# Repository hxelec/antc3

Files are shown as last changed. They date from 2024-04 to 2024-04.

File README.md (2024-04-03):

These are the files for the 150g antweight combat robot I recently made. I made an all-in-one robot controller, which is, in my opinion, a better alternative to the Malenki-Nano and Malenki-HV, and a very low-cost ESP-NOW remote. The high-quality PCBs for this project were manufactured by PCBWay, and if you use my link to sign up: https://pcbway.com/g/x5f10h, you can get $5 off your first order and help support this (partially) open-source development. You can check out the video for this project on my YouTube channel: https://youtube.com/@hxtec32?si=qvrlxVD-KIIIB9TC
The code does not have failsafe, and doesn't drive the robot fully straight by the way, but feel free to use it as a reference for bidirectional ESP-NOW communication. I would recommend reading this article too, as I adapted the code for my own use case: https://randomnerdtutorials.com/esp-now-two-way-communication-esp32/
By the way, you need the necessary Arduino files for a T-QT Pro before using my code, because it won't work if otherwise. The T-QT Pro is great for this project.

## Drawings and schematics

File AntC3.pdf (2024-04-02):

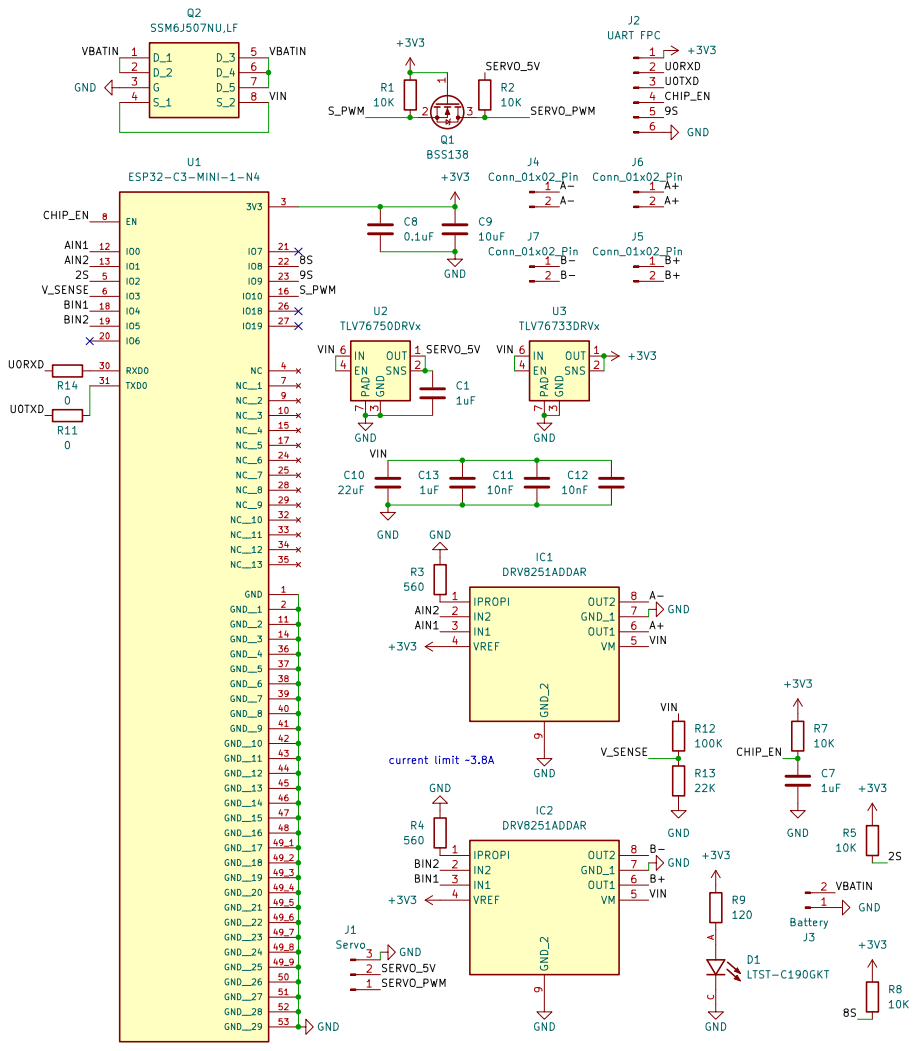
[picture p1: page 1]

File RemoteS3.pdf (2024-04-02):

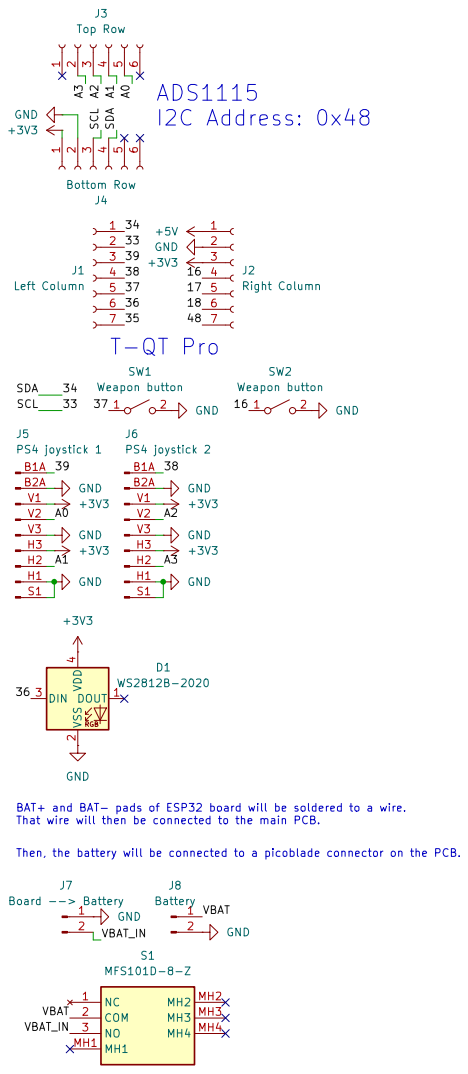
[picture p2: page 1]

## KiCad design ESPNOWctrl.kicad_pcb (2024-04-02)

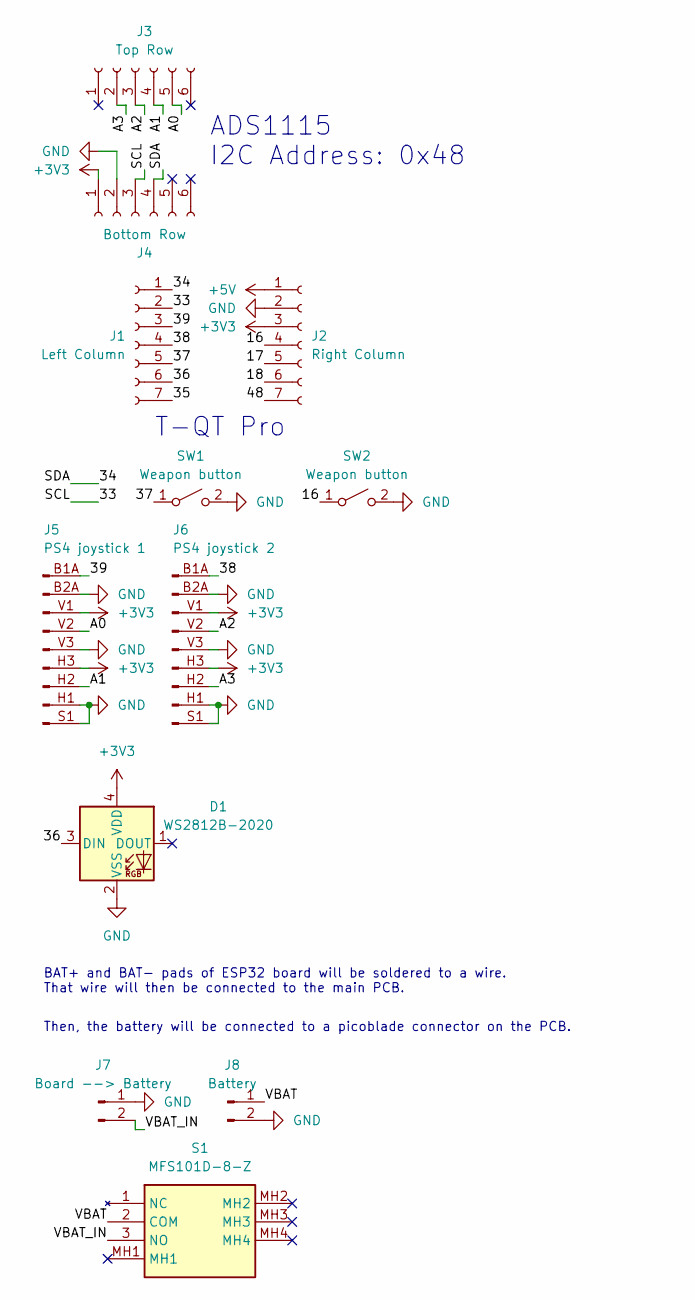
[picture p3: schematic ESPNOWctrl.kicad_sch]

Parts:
D1: WS2812B-2020; LED_WS2812B-2020_PLCC4_2.0x2.0mm
J1: Left Column; PinSocket_1x07_P2.54mm_Vertical
J2: Right Column; PinSocket_1x07_P2.54mm_Vertical
J3: Top Row; PinSocket_1x06_P2.54mm_Vertical
J4: Bottom Row; PinSocket_1x06_P2.54mm_Vertical
J5: PS4 joystick 1; PS4_joystick
J6: PS4 joystick 2; PS4_joystick
J7: Board --> Battery; JST_PH_B2B-PH-K_1x02_P2.00mm_Vertical
J8: Battery; JST_PH_B2B-PH-K_1x02_P2.00mm_Vertical
S1: MFS101D-8-Z; MFS101D8Z; Manufacturer_Part_Number MFS101D-8-Z
SW1, SW2: Weapon button; SW_SPST_Omron_B3F-315x_Angled

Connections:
+3V3: D1.4 (VDD), J2.3, J4.1, J5.H3 (Pin_6), J5.V1 (Pin_3), J6.H3 (Pin_6), J6.V1 (Pin_3)
+5V: J2.1
/16: J2.4, SW2.1 (A)
/17: J2.5
/18: J2.6
/33: J1.2, J4.3
/34: J1.1, J4.4
/35: J1.7
/36: D1.3 (DIN), J1.6
/37: J1.5, SW1.1 (A)
/38: J1.4, J6.B1A (Pin_1), J6.B1B (Pin_1)
/39: J1.3, J5.B1A (Pin_1), J5.B1B (Pin_1)
/48: J2.7
/A0: J3.5, J5.V2 (Pin_4)
/A1: J3.4, J5.H2 (Pin_7)
/A2: J3.3, J6.V2 (Pin_4)
/A3: J3.2, J6.H2 (Pin_7)
/VBAT: J8.1, S1.2 (COM)
/VBAT_IN: J7.2, S1.3 (NO)
GND: D1.2 (VSS), J2.2, J4.2, J5.B2A (Pin_2), J5.B2B (Pin_2), J5.H1 (Pin_8), J5.S1 (Pin_9), J5.S2 (Pin_9), J5.S3 (Pin_9), J5.S4 (Pin_9), J5.V3 (Pin_5), J6.B2A (Pin_2), J6.B2B (Pin_2), J6.H1 (Pin_8), J6.S1 (Pin_9), J6.S2 (Pin_9), J6.S3 (Pin_9), J6.S4 (Pin_9), J6.V3 (Pin_5), J7.1, J8.2, SW1.2 (B), SW2.2 (B)

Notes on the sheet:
T-QT Pro
ADS1115 I2C Address: 0x48
BAT+ and BAT- pads of ESP32 board will be soldered to a wire. That wire will then be connected to the main PCB.
Then, the battery will be connected to a picoblade connector on the PCB.

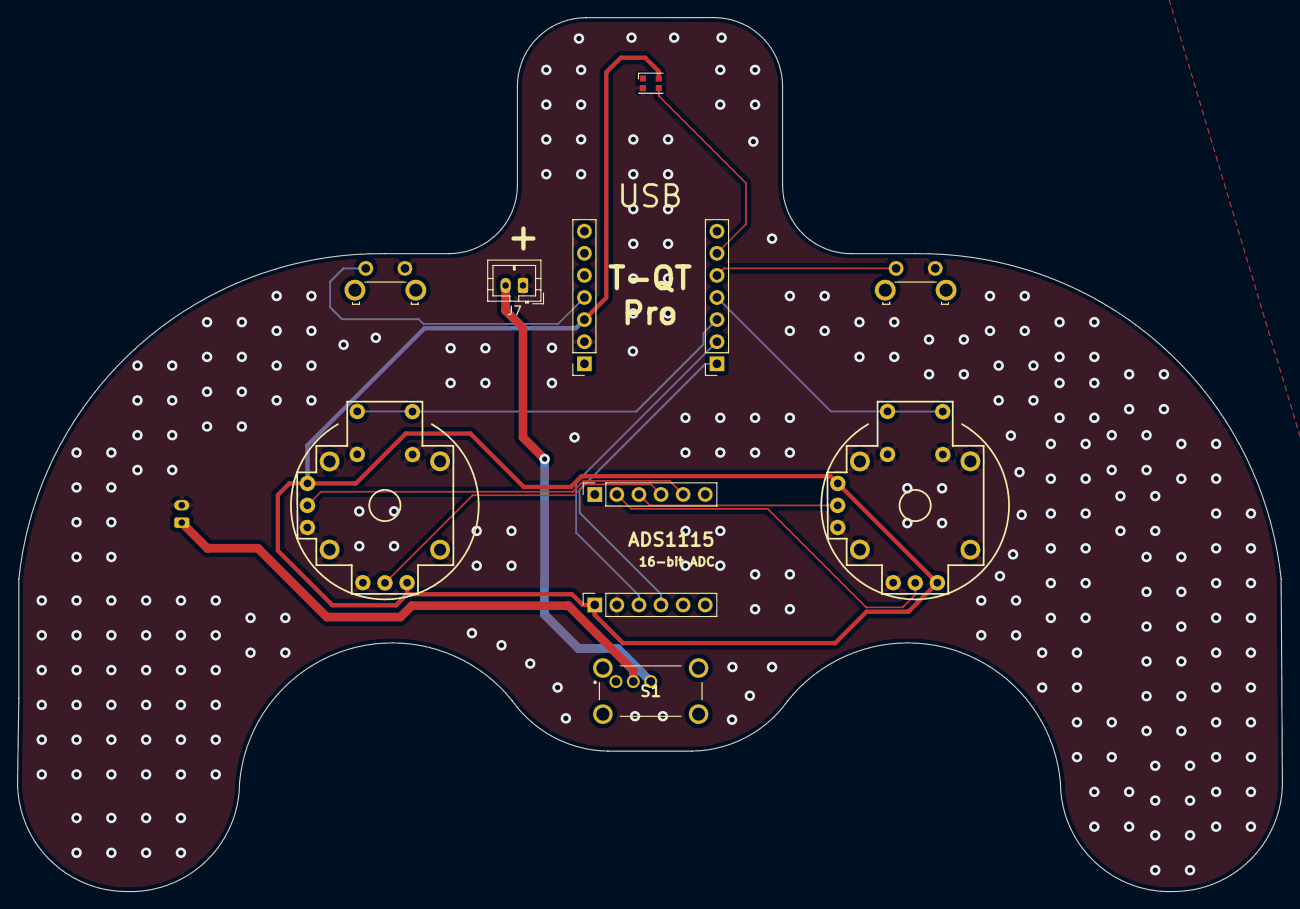
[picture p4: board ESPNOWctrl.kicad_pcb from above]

Board: 2 copper layers, 145.4 x 100.5 mm, 12 parts (1 on the bottom side), 15 nets.

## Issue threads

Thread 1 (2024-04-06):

BLE Vs Bluetooth Classic

nevsie, 2024-04-06:
I love everything you have done here, congrats.
I am doing similar with a esp32 D1 mini board, but external esc and bec. The reason I chose this board is to use cheap gaming controllers, but they require Bluetooth classic.

Yes, it means a bigger heavier board than BLE..
But I wondered if you'd consider a variant of your board with this on board?

I then use the Bluepad32 library as the basis for connecting the controller. This allows everything from Xbox, pc, PS3, PS4, PS4, android, iOS, switch, Wii, etc. I'd love to drive with the Wii wheel!

I hope you'd consider.
Thanks, N

hxelec, 2024-04-13:
Hi nevsie, I would be happy to consider a variant of this board with a classic ESP32 chip, using the ESP32-PICO-MINI-02 module, but unfortunately, I would have no use for it over just the ESP32-C3 I'm using, since ESP-NOW communication (which works with every ESP chip) is being used for my application. If you'd like me to design you a board with the ESP32 chip instead of the ESP32-C3, in exchange for payment, and then send you all the manufacturing files once I'm done, I would be happy to do that, and you can contact me: brixdownunder@gmail.com.

nevsie, 2024-04-13:
Hi and thanks for your reply.
Completely understand your direction, and decisions.

My mentality is that using existing gaming controllers is a great, familiar, way to control the bots. They are very cheap even if you do not have old ones in the draw somewhere to recycle.

I have since been pushed towards the ESP Pico-d4 chip, as this does both BLE and classic, and a tiny ceramic antenna.

Thanks for the offer of design. But like you and many others, I am intending to open source it so will be trying to keep costs down.

Good luck with yours, I'd love to see you controller expand. N

nevsie, 2024-04-13:
Closing this now.

Closed 2024-04-13.

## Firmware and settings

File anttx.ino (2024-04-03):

#include <TFT_eSPI.h>
#include <SPI.h>
#include <Adafruit_NeoPixel.h>
#include <esp_now.h>
#include <WiFi.h>
#include "logo.h"
#include <Wire.h>
#include <Adafruit_ADS1X15.h>
#include <ezButton.h>

TFT_eSPI tft = TFT_eSPI();

Adafruit_NeoPixel pixels(1, 36, NEO_GRB + NEO_KHZ800);

Adafruit_ADS1115 ads;

const int BAT_SENSE = 4;

unsigned long targetTime = 0;

uint8_t broadcastAddress[] = {0x30, 0x30, 0xF9, 0xFE, 0x62, 0x54};

const int SERVO_PIN = 37;

const int LEFT_BUTTON = 16;

const int jRight = 38;

const int jLeft = 39;

int currentSpeed = 1;

String macro = String("C");

int motor_A;
int motor_B;
bool servo_status;

int espnowpercent;

typedef struct MotorData {
  int a;
  int b;
  int c;
} MotorData;

typedef struct BatteryCheck {
  int batt;
} BatteryCheck;

MotorData motors;
BatteryCheck battery;

ezButton button_l(jLeft);
ezButton button_r(jRight);

esp_now_peer_info_t peerInfo;

void OnDataSent(const uint8_t *mac_addr, esp_now_send_status_t status) {
  Serial.print("\r\nLast Packet Send Status:\t");
  Serial.println(status == ESP_NOW_SEND_SUCCESS ? "Delivery Success" : "Delivery Fail");
}

void OnDataRecv(const uint8_t * mac, const uint8_t *incomingData, int len) {
  memcpy(&battery, incomingData, sizeof(battery));
  Serial.print("Bytes received: ");
  Serial.println(len);
  espnowpercent = battery.batt;
}

void setup(void) {
  pinMode(jLeft, INPUT_PULLUP);
  pinMode(jRight, INPUT_PULLUP);
  pinMode(SERVO_PIN, INPUT_PULLUP);
  pinMode(LEFT_BUTTON, INPUT_PULLUP);
  tft.init();
  tft.setRotation(0);
  tft.fillScreen(TFT_BLACK);
  pixels.begin();
  pixels.setBrightness(20);
  button_l.setDebounceTime(50);
  button_r.setDebounceTime(50);
  WiFi.mode(WIFI_STA);
  Wire.begin(34, 33);
  if (!ads.begin()) {
    Serial.println("Failed to initialize ADS1115");
    while (1);
  }
  if (esp_now_init() != ESP_OK) {
    Serial.println("Error initializing ESP-NOW");
    return;
  }
  esp_now_register_send_cb(OnDataSent);

  memcpy(peerInfo.peer_addr, broadcastAddress, 6);
  peerInfo.channel = 0;  
  peerInfo.encrypt = false;
  
  // Add peer        
  if (esp_now_add_peer(&peerInfo) != ESP_OK){
    Serial.println("Failed to add peer");
    return;
  }
  esp_now_register_recv_cb(OnDataRecv);
}

void loop() {
  button_l.loop();
  button_r.loop();

  if(button_l.isReleased()) {
    if (currentSpeed > 0) {
      currentSpeed--;
    }
  }

  if(button_r.isReleased()) {
    if (currentSpeed < 3) {
      currentSpeed++;
    }
  }

  getReadings();

  updateDisplay();

  motors.a = motor_A;
  motors.b = motor_B;
  motors.c = digitalRead(SERVO_PIN);

  esp_err_t result = esp_now_send(broadcastAddress, (uint8_t *) &motors, sizeof(motors));
  
  if (result == ESP_OK) {
    Serial.println("Sent with success");
  }
  else {
    Serial.println("Error sending the data");
  }
}

void getReadings() {
  if (digitalRead(LEFT_BUTTON) == HIGH) {
    if (currentSpeed == 0) {
      motor_A = map(ads.readADC_SingleEnded(0), 0, 16000, 8000, 10000);
      motor_B = map(ads.readADC_SingleEnded(2), 0, 16000, 7500, 9500);
    } else if (currentSpeed == 1) {
      motor_A = map(ads.readADC_SingleEnded(0), 0, 16000, 5000, 11000);
      motor_B = map(ads.readADC_SingleEnded(2), 0, 16000, 4500, 10500);
    } else if (currentSpeed == 2) {
      motor_A = map(ads.readADC_SingleEnded(0), 0, 16000, 3000, 13000);
      motor_B = map(ads.readADC_SingleEnded(2), 0, 16000, 2500, 12500);
    } else if (currentSpeed == 3) {
      motor_A = ads.readADC_SingleEnded(0);
      motor_B = ads.readADC_SingleEnded(2);
    }
    macro = String("C");
  } else {
    motor_A = 16000;
    motor_B = 16000;
    macro = String("S");
  }
  servo_status = digitalRead(SERVO_PIN);
}

void updateDisplay() {
  pixels.fill(0xFF0000);
  tft.fillScreen(TFT_BLACK);
  tft.setRotation(0);

  tft.setTextSize(4);
  tft.setTextColor(TFT_WHITE);
  tft.setCursor(53, 10);
  tft.print(macro); //macro indicator

  tft.setTextSize(2);
  int remotePercentage = map(analogRead(BAT_SENSE), 2100, 2600, 0, 100);
  if (remotePercentage > 40) {
    tft.setTextColor(TFT_GREEN);
  } else {
    tft.setTextColor(TFT_RED);
  }
  tft.setCursor(0, 5);
  tft.print(remotePercentage);

  tft.setTextSize(2);
  String outbat = "  ";
  if (espnowpercent > 99) {
    outbat = "FC";
  } else if (espnowpercent > 40) {
    tft.setTextColor(TFT_GREEN);
    outbat = String(espnowpercent);
  } else {
    tft.setTextColor(TFT_RED);
    if (espnowpercent > 10) {
      outbat = String(espnowpercent);
    } else {
      outbat = "0" + String(espnowpercent);
    }
  }
  tft.setCursor(102, 5);
  tft.print(outbat);

  tft.drawXBitmap(43, 46, logo, logoWidth, logoHeight, TFT_WHITE);
  
  tft.setTextSize(4);
  tft.setTextColor(TFT_WHITE);
  tft.setCursor(53, 90);
  if (currentSpeed == 0) {
    tft.print("L");
  } else if (currentSpeed == 1) {
    tft.print("M");
  } else if (currentSpeed == 2) {
    tft.print("H");
  } else {
    tft.print("X");
  }
}

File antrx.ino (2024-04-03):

#include <esp_now.h>
#include <WiFi.h>

const int AIN1 = 0;
const int AIN2 = 1;
const int V_SENSE = 3;
const int BIN1 = 4;
const int BIN2 = 5;
const int servoPin = 10;

uint8_t broadcastAddress[] = {0xF4, 0x12, 0xFA, 0x59, 0xDD, 0x50};

int incomingA;
int incomingB;
int sesrvo;

int outgoingbat;

unsigned long currentMillis = millis();

typedef struct MotorData {
  int a;
  int b;
  int c;
} MotorData;

typedef struct BatteryCheck {
  int batt;
} BatteryCheck;

MotorData motors;
BatteryCheck battery;

esp_now_peer_info_t peerInfo;

void OnDataSent(const uint8_t *mac_addr, esp_now_send_status_t status) {
  Serial.print("\r\nLast Packet Send Status:\t");
  Serial.println(status == ESP_NOW_SEND_SUCCESS ? "Delivery Success" : "Delivery Fail");
}

void OnDataRecv(const uint8_t * mac, const uint8_t *incomingData, int len) {
  memcpy(&motors, incomingData, sizeof(motors));
  Serial.print("Bytes received: ");
  Serial.println(len);
  incomingA = motors.a;
  incomingB = motors.b;
  sesrvo = motors.c;
}

void setup() {
  // put your setup code here, to run once:
  pinMode(AIN1, OUTPUT);
  pinMode(AIN2, OUTPUT);
  pinMode(BIN1, OUTPUT);
  pinMode(BIN2, OUTPUT);
  pinMode(V_SENSE, INPUT);
  pinMode(servoPin, OUTPUT);
  Serial.begin(115200);
  ledcSetup(0, 2000, 12);
  ledcSetup(1, 2000, 12);
  ledcSetup(2, 2000, 12);
  ledcSetup(3, 2000, 12);
  ledcSetup(4, 330, 8);
  ledcAttachPin(AIN1, 0);
  ledcAttachPin(AIN2, 1);
  ledcAttachPin(BIN1, 2);
  ledcAttachPin(BIN2, 3);
  ledcAttachPin(10, 4);
  //servo likes the range 87 - 140.
  WiFi.mode(WIFI_STA);
  if (esp_now_init() != ESP_OK) {
    Serial.println("Error initializing ESP-NOW");
    return;
  }
  esp_now_register_send_cb(OnDataSent);

  memcpy(peerInfo.peer_addr, broadcastAddress, 6);
  peerInfo.channel = 0;  
  peerInfo.encrypt = false;
  
  // Add peer        
  if (esp_now_add_peer(&peerInfo) != ESP_OK){
    Serial.println("Failed to add peer");
    return;
  }
  // Register for a callback function that will be called when data is received
  esp_now_register_recv_cb(OnDataRecv);
}

void loop() {
  int A_speed = map(incomingA, 0, 16000, 3200, -3200);
  if (A_speed < 500 && A_speed > -500) {
    A_speed = 0;
  }
  if (A_speed > 4095) {
    A_speed = 4095;
  }
  if (A_speed < -4095) {
    A_speed = -4095;
  }
  if (A_speed > 0) {
    ledcWrite(0, abs(A_speed));
    ledcWrite(1, 0);
  } else {
    ledcWrite(1, abs(A_speed));
    ledcWrite(0, 0);  
  }

  int B_speed = map(incomingB, 0, 16000, 4095, -4095);
  if (B_speed < 500 && B_speed > -500) {
    B_speed = 0;
  }
  if (B_speed > 4095) {
    B_speed = 4095;
  }
  if (B_speed < -4095) {
    B_speed = -4095;
  }
  if (B_speed > 0) {
    ledcWrite(2, abs(B_speed));
    ledcWrite(3, 0);
  } else {
    ledcWrite(3, abs(B_speed));
    ledcWrite(2, 0);  
  }

  if (sesrvo == 0) {
    ledcWrite(4, 140);
  } else {
    ledcWrite(4, 89);
  }

  if (millis() - currentMillis > 1000) {
    battery.batt = map(analogRead(V_SENSE), 1673, 2067, 0, 100);

    esp_err_t result = esp_now_send(broadcastAddress, (uint8_t *) &battery, sizeof(battery));
    
    if (result == ESP_OK) {
      Serial.println("Sent with success");
    }
    else {
      Serial.println("Error sending the data");
    }
    currentMillis = millis();
  }
}
